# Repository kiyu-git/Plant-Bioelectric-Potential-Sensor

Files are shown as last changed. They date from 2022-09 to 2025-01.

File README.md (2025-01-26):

[日本語](https://github.com/kiyu-git/Plant-Bioelectric-Potential-Sensor) | [English](/README-en.md)

# Plant Bioelectric Potential Sensor

植物生体電位測定器

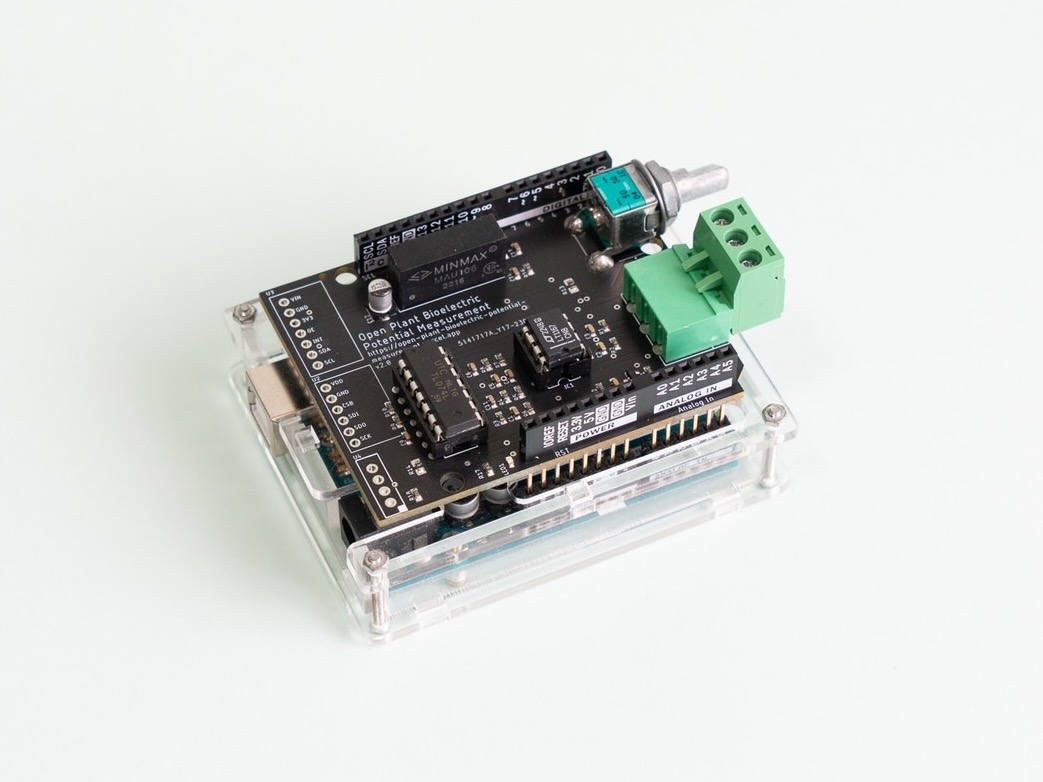
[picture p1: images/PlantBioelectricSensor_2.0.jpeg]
Plant-Bioelectric-Potential-Sensor


## Overview

開発した植物生体電位測定器の回路図等をまとめています。

なお、このリポジトリは、『[植物生体電位測定をオープンにするプロジェクト](https://open-plant-bioelectric-potential-measurement.vercel.app)』の一部です。

[こちら](https://kiyu-shop.booth.pm)からプロジェクトへの寄付、PCB 基板およびパーツのセットの購入ができます。

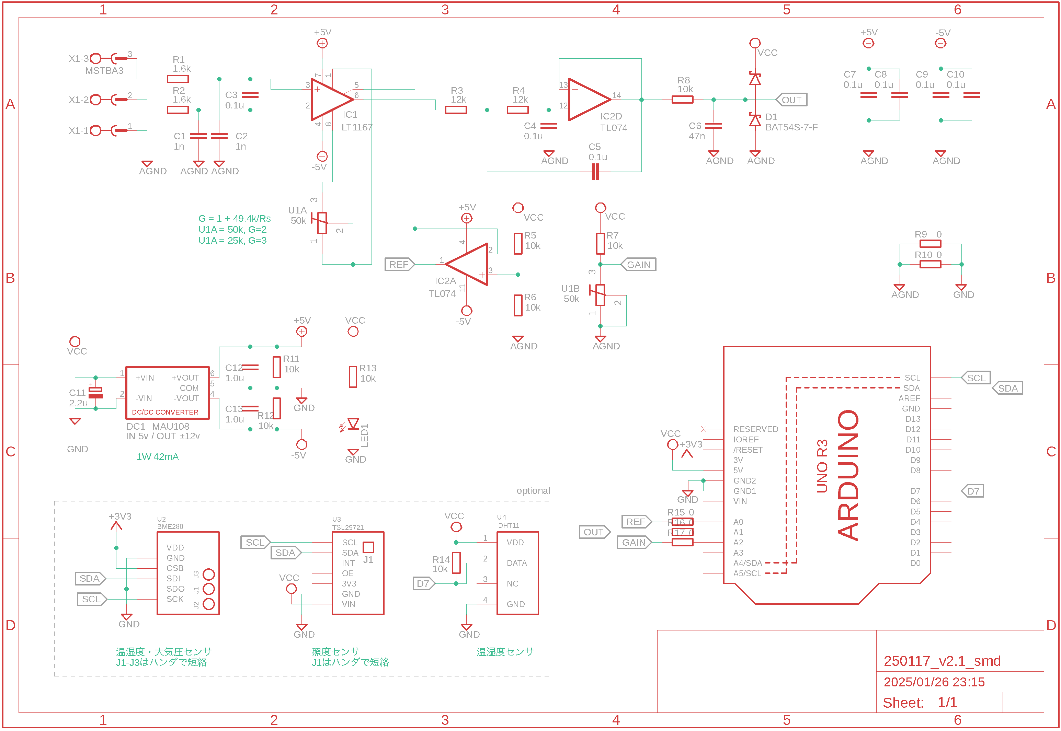
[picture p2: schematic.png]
Plant-Bioelectric-Potential-Sensor-schematic

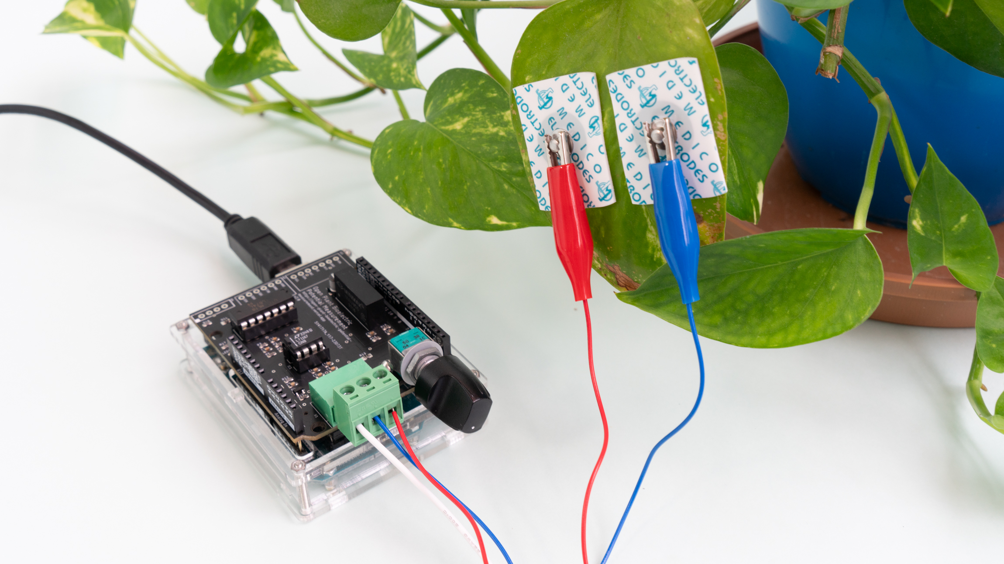
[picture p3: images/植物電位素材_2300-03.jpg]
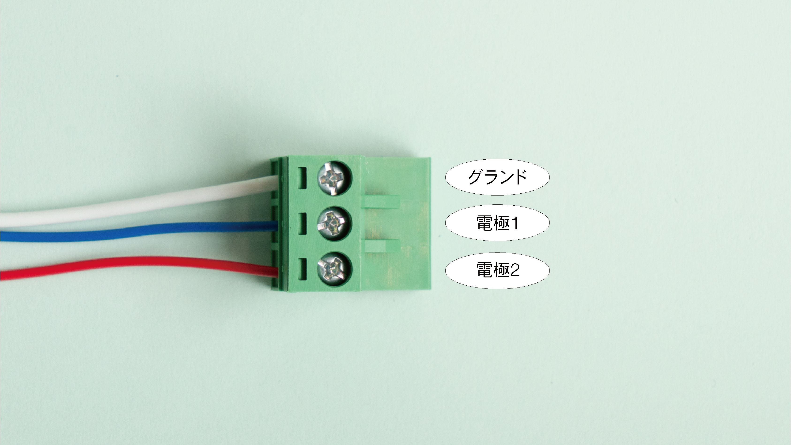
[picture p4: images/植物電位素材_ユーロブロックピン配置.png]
 

## Revision history

### v1.0.0

- 最初のモデル

### v1.1.0

- 部品の番号を振り直し
- [リンク](https://github.com/kiyu-git/Plant-Bioelectric-Potential-Sensor/tree/1f7dd3a86559b1f9ea93b5415610122e70b9b8db)

### v1.1.1

- 信号処理モジュール
  - 回路図を清書
  - 一部の抵抗の値を変更

### v2.0

- Arduino シールド規格に合わせ、拡張性を高めた。
- 回路構成の大幅な変更をおこなった。

### v2.1

- DC-DC コンバータを MAU 106 から MAU108 に変更
  - Arduino の ADC のフルレンジ（0 - 5V）での測定が可能になった。

## Requirement

植物生体電位測定器の組み立てに必要な部品一覧

**測定基板**

回路図から読み取ってください

**測定用ケーブル**

| Device Name | Value / Type | Need | Note |
| --- | --- | ---- | --- |
| ユーロブロックターミナル | | 1 | |
| 導線 | ~ 50cm | 3 | 赤青黒の 3 色があるとわかりやすい |
| みの虫クリップ | small | 3 | 赤青黒の 3 色があるとわかりやすい |
| 釘 | | 1 | 導電性のもの |
| 電極パッド | | 2 | 心電パッドなどを流用 |

## Usage

このリポジトリは、『[植物生体電位測定をオープンにするプロジェクト](https://open-plant-bioelectric-potential-measurement.vercel.app)』の一部です。

[植物生体電位測定の例 (YouTube)](https://www.youtube.com/embed/kBemMpVNFAs?si=k8SLGgCpc5z7__u_)

## Reference

- Forest Symphony: [https://special.ycam.jp/interlab/projects/forestsymphony.html](https://special.ycam.jp/interlab/projects/forestsymphony.html)
- LT1167 DataSheet: https://www.analog.com/media/en/technical-documentation/data-sheets/1167fc.pdf
- [and more...](https://docs.google.com/presentation/d/1Tm0e-mBNrTchN6YlGpvvomUZfy79yOtrTSNHG-l_jFg/edit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)

## Donation

[こちら](https://kiyu-shop.booth.pm/items/4141049)からプロジェクトへの寄付ができます。

## Author

質問等は twitter または[Issues](https://github.com/kiyu-git/Plant-Bioelectric-Potential-Sensor/issues)より

twitter: https://twitter.com/kyu_yukirinrin

website: https://untamable.work

## License

[GPL-3.0 license](https://github.com/kiyu-git/Plant-Bioelectric-Potential-Sensor/blob/main/LICENSE)

※ 共同研究や、案件依頼・相談も受け付けております。twitter DM または website よりご連絡ください。

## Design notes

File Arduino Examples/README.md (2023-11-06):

# Arduino Examples

## Basic

植物生体電位の増幅後の値、実際の値を測定し、シリアル通信で送信するプログラム

## Advanced

### upload_SORACOM

LTE モジュールと IoT クラウドサービス を利用したウェブ上でのデータ可視化の例。

SORACOM が販売している Arduino 用 LTE シールド LTE-M Shield for Arduino を植物生体電位測定器 と組み合わせ、SORACOM Harvest にデータを送信。

なお、LTE-M Shield for Arduino はアナログ入力ピン A1 を使用しており、起動すると植物生体電位を測定できない。 そのため、Reset ピンとデジタル入出力ピン D7 を接続し、A1 の値を読み取った後に、LTE モジュールを起動、データがアップロードできたら Reset し、A1 を解放している。

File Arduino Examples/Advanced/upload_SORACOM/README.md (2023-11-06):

# upload_SORACOM

植物生体電位測定器と LTE-M Shield for Arduino を利用するスケッチ例です。

This repository provides example sketches using plant bioelectric potential metar and LTE-M Shield for Arduino.

[arduino-dragino-unified](https://github.com/soracom-labs/arduino-dragino-unified/tree/main) を参考にしています。

## License

このリポジトリ配下に属するスケッチは [MIT ライセンス](./LICENSE-MIT)が適用されます。なお、スケッチが利用するライブラリはそれぞれのライセンスに従います。
たとえば、セルラー通信に利用する [TinyGSM](https://github.com/vshymanskyy/TinyGSM) ライブラリは [LGPL v3.0](./LICENSE-LGPLv3) ライセンスが適用されます。

The sketches in this repository are released under [The MIT License](./LICENSE-MIT), and libraries used by these sketches are subject to their respective licenses.
For example, the [TinyGSM](https://github.com/vshymanskyy/TinyGSM) library used for cellular communications is released under the [LGPL v3.0](./LICENSE-LGPLv3) license.

## Warning

このリポジトリ配下のスケッチは開発例であり、動作を保証するものではありません。また、このスケッチに記載されている内容の商用利用を想定していません。
利用にあたってはご自身の責任の範囲においてご利用ください。

The sketches in this repository are examples only and are not guaranteed to work. In addition, the content of this sketch is not intended for commercial use.
Please use them at your own risk.

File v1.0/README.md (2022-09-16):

## Requirement

植物生体電位測定器の組み立てに必要な部品一覧

部品番号 v1.0

| 測定部 | | | |
| --- | ----- | --- | --- |
| Part | Value | 備考 | URL |
| C1 | 47p | | |
| C2 | 47p | | |
| C3 | 0.1u  | | |
| C4 | 0.1u  | | |
| C8 | 0.1u  | | |
| IC1 | | LM324 | [参考](https://akizukidenshi.com/catalog/g/gI-14055/) |
| IC2 | | LT1167 | [参考](https://akizukidenshi.com/catalog/g/gI-02789/) |
| JP3 | | 5 連 pinheader（背が高いの推奨） | |
| LED2 | | 3mm LED（赤） | |
| R1 | 1k | | |
| R2 | 1k | | |
| R3 | 100k  | | |
| R4 | 10k | | |
| R5 | 10k | | |
| R6 | 4.7k  | | |
| R7 | 10k | | |
| R8 | 10k | | |
| R9 | 10k | | |
| R10 | 50k | 半固定抵抗 | |
| R12 | 100k  | | |
| R16 | 68k | | |
| R17 | 1k | | |
| R21 | 10k | | |
| R22 | 10k | | |
| U$2 | | 3.5mm ステレオミニジャック MJ-354W-SG | [参考](https://akizukidenshi.com/catalog/g/gC-15403/) |
| U$3 | | 2 連ボリューム | [参考](https://akizukidenshi.com/catalog/g/gP-12578/) |

| 電源部 | | | |
| --- | ----- | --- | --- |
| Part | Value | 備考 | URL |
| C9 | 47u | | |
| C10 | 47u | | |
| C11 | 47u | | |
| C12 | 0.1u  | | |
| C13 | 0.1u  | | |
| DC1 | | IN 5v/ OUT ±5v DC-DC コンバーター（MAU106） | [参考](https://akizukidenshi.com/catalog/g/gM-04133/) |
| JP1 | | 5 連 pinheader（背が高いの推奨） | |
| JP2 | | ※必要なし | |
| MODUL1 | | Arduino Nano | |
| R13 | 10k | | |
| R14 | 10k | | |

| 測定用銅線 | | | |
| --- | ----- | --- | --- |
| Part | Value | 備考 | URL |
| | | 3.5mm ステレオミニプラグ | |
| | | 銅線 | |
| | | ワニ口クリップ | |

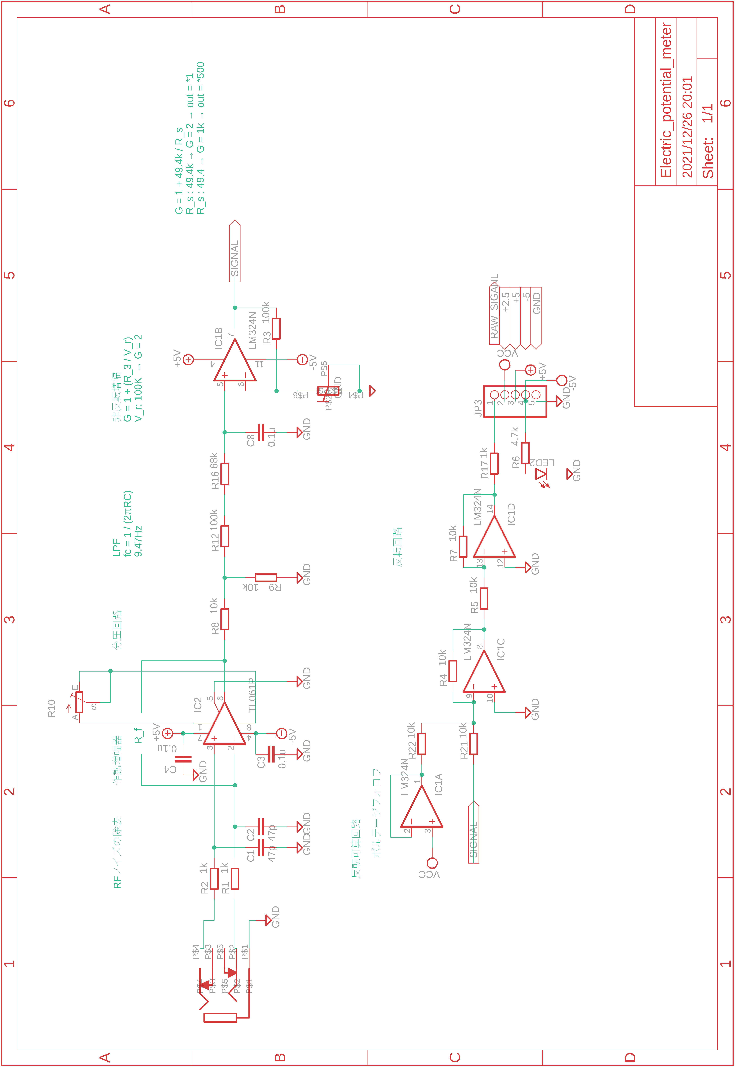
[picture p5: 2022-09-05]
v1.0/Signal Processing Module/images/circuit_sp_module.png

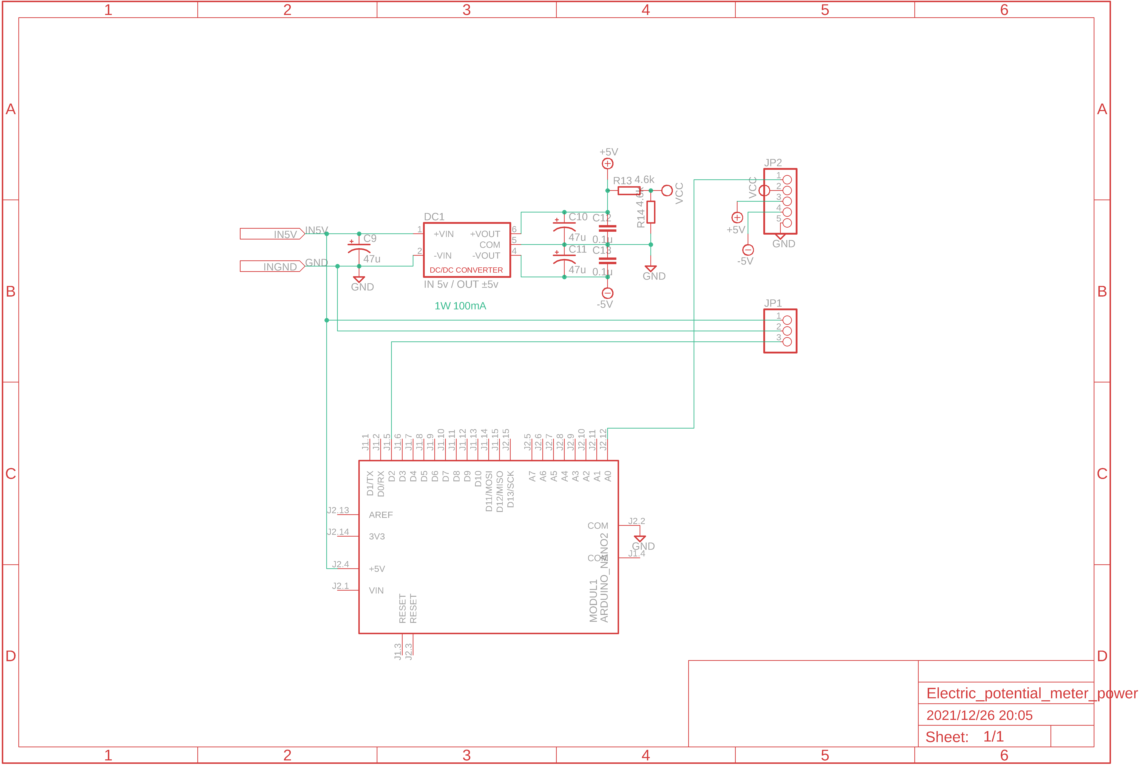
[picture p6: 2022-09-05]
v1.0/Power and ADC Module/images/circuit_power_module.png

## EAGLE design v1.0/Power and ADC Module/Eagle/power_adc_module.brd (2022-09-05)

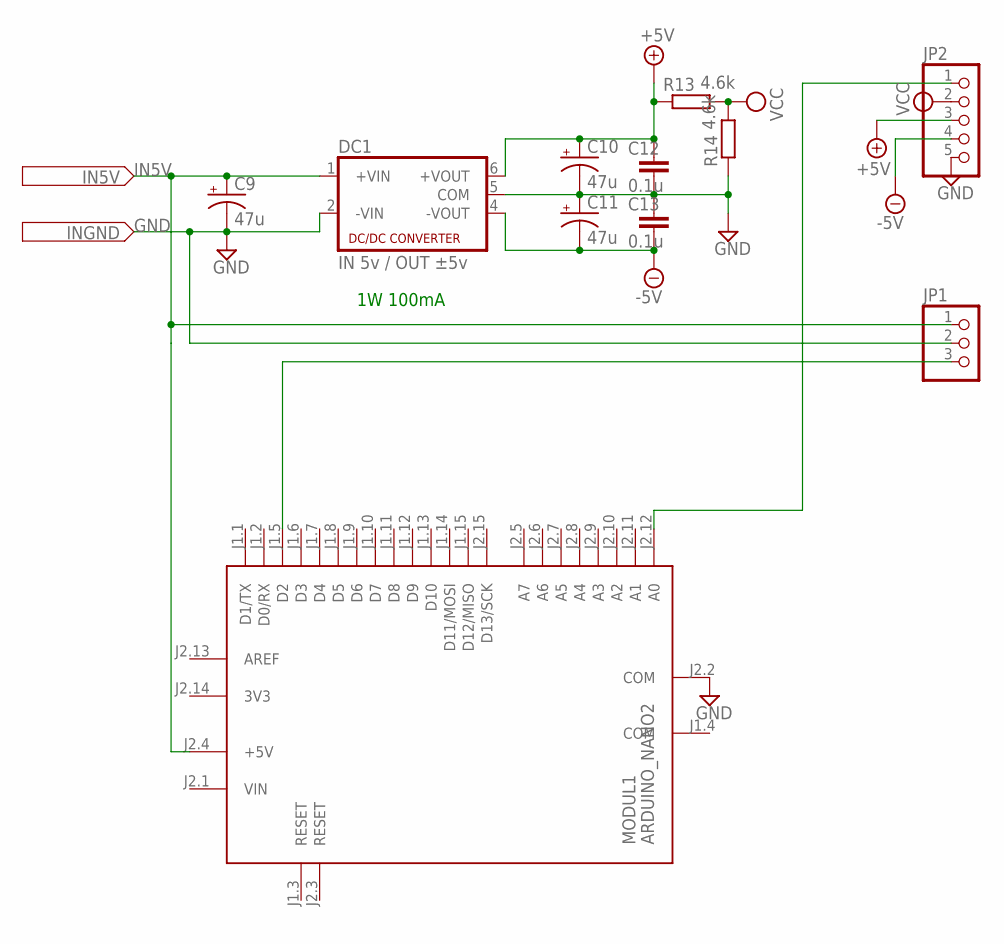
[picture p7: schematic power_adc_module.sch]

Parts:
C9, C10, C11: 47u; E2,5-5
C12, C13: 0.1u; C025-024X044
DC1: IN 5v / OUT ±5v; NMA
JP1: PINHD-1X3; 1X03
JP2: PINHD-1X5; 1X05
MODUL1: ARDUINO_NANO2
R13, R14: 4.6k; 0204/7

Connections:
3V3: MODUL1.J2.14 (3V3)
+5V: C10.+, C12.1, DC1.6 (+VOUT), JP2.3, R13.1
-5V: C11.-, C13.2, DC1.4 (-VOUT), JP2.4
AREF: MODUL1.J2.13 (AREF)
COM: MODUL1.J1.4 (COM)
GND: C9.-, C10.-, C11.+, C12.2, C13.1, DC1.2 (-VIN), DC1.5 (COM), JP1.2, JP2.5, MODUL1.J2.2 (COM), R14.1
IN5V: C9.+, DC1.1 (+VIN), JP1.1, MODUL1.J2.4 (+5V)
unnamed: JP2.1, MODUL1.J2.12 (A0)
unnamed: JP1.3, MODUL1.J1.5 (D2)
VCC: JP2.2, R13.2, R14.2
VIN: MODUL1.J2.1 (VIN)

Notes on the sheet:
1W 100mA

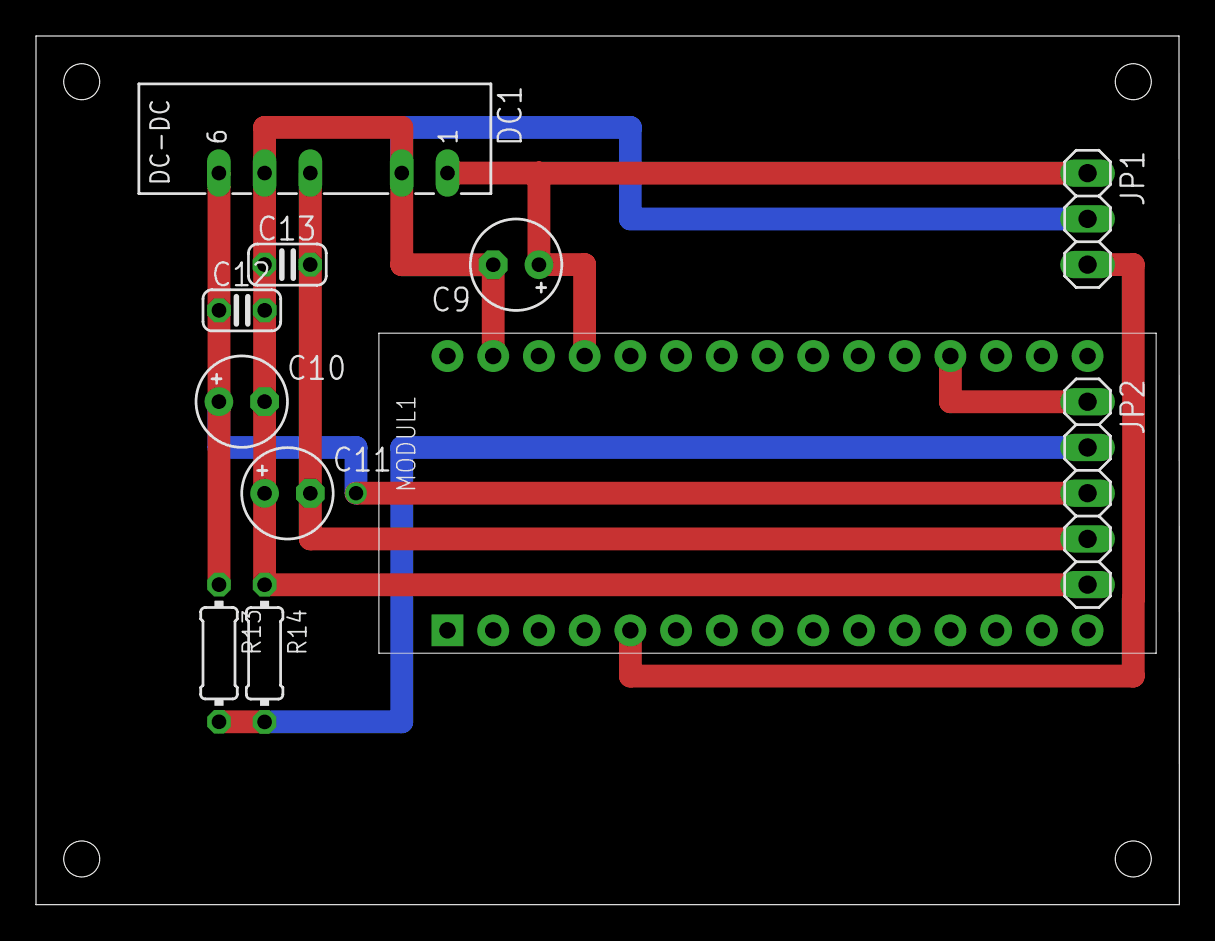
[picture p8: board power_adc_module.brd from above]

Board: 2 copper layers, 63.5 x 48.3 mm, 11 parts (0 on the bottom side), 7 nets.

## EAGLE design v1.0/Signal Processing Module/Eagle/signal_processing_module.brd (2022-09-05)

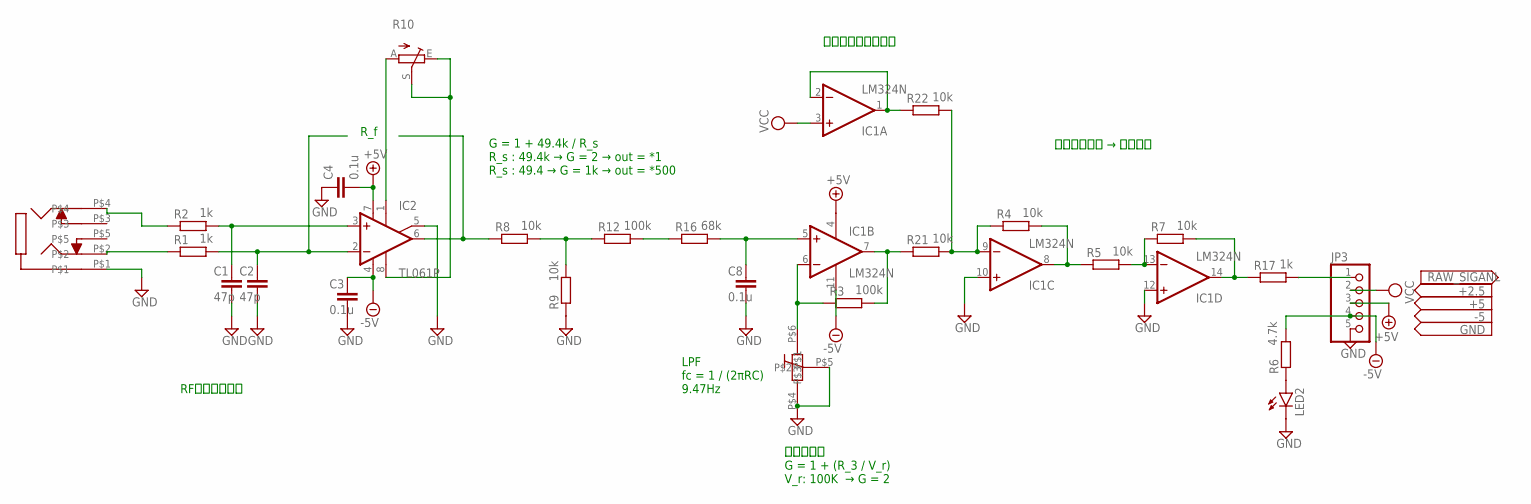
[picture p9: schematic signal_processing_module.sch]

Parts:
C1, C2: 47p; C025-024X044
C3, C4, C8: 0.1u; C025-024X044
IC1: LM324N; DIL14
IC2: TL061P; DIL08
JP3: PINHD-1X5; 1X05
LED2: LED3MM
R1, R2, R17: 1k; 0204/7
R3, R12: 100k; 0204/7
R4, R5, R7, R8, R9, R21, R22: 10k; 0204/7
R6: 4.7k; 0204/7
R10: TRIM_EU-RS3; RS3
R16: 68k; 0204/7
U$2: MJ-354W-SG
U$3: VR_2CH; 2CH_VR

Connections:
+5V: C4.2, IC1.4 (V+), IC2.7 (V+), JP3.3
-5V: C3.1, IC1.11 (V-), IC2.4 (V-), JP3.4, R6.2
GND: C1.2, C2.2, C3.2, C4.1, C8.2, IC1.10 (+IN), IC1.12 (+IN), IC2.5 (ON2), JP3.5, LED2.K (C), R9.1, U$2.P$1, U$3.P$4, U$3.P$5
unnamed: R1.1, U$2.P$2
unnamed: R2.1, U$2.P$4
unnamed: C1.1, IC2.3 (+IN), R2.2
unnamed: C2.1, IC2.2 (-IN), R1.2
unnamed: IC2.8 (OPT), R10.E, R10.S
unnamed: IC2.6 (OUT), R8.1
unnamed: IC2.1 (ON1), R10.A
unnamed: R12.2, R16.1
unnamed: IC1.13 (-IN), R5.2, R7.1
unnamed: JP3.1, R17.2
unnamed: LED2.A, R6.1
unnamed: IC1.6 (-IN), R3.1, U$3.P$6
unnamed: IC1.8 (OUT), R4.2, R5.1
unnamed: IC1.14 (OUT), R7.2, R17.1
unnamed: C8.1, IC1.5 (+IN), R16.2
unnamed: R8.2, R9.2, R12.1
unnamed: IC1.1 (OUT), IC1.2 (-IN), R22.1
unnamed: IC1.9 (-IN), R4.1, R21.2, R22.2
RAW_SIGNAL: IC1.7 (OUT), R3.2, R21.1
VCC: IC1.3 (+IN), JP3.2

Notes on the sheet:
G = 1 + 49.4k / R_s R_s : 49.4k → G = 2 → out = *1 R_s : 49.4 → G = 1k → out = *500
LPF fc = 1 / (2πRC) 9.47Hz
R_f
RFノイズの除去
非反転増幅 G = 1 + (R_3 / V_r) V_r: 100K → G = 2
ボルテージフォロワ
反転可算回路 → 反転回路

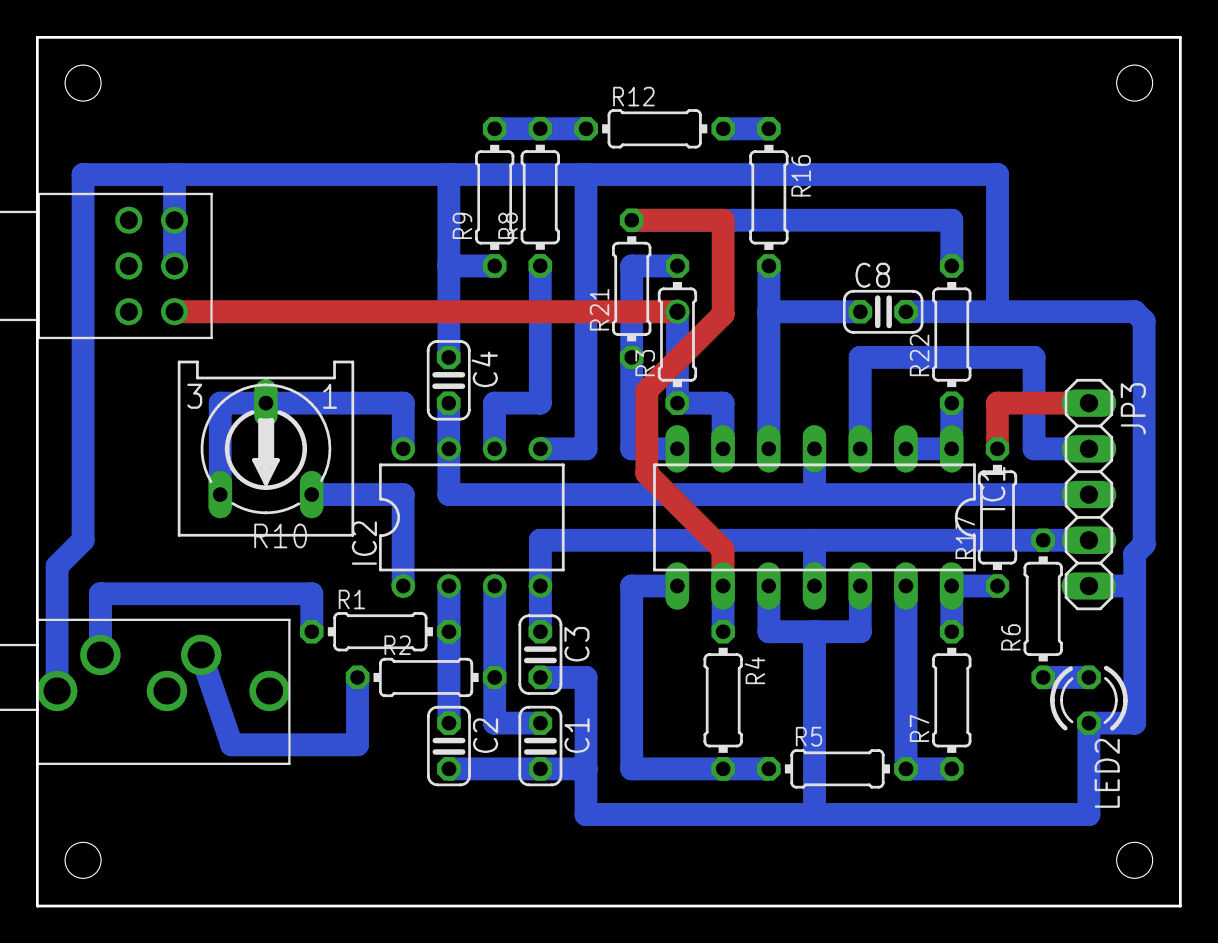
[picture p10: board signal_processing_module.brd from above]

Board: 2 copper layers, 63.5 x 48.3 mm, 26 parts (0 on the bottom side), 23 nets.

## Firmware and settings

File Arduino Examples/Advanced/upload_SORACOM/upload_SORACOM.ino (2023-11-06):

/*
 * 
 * This software is released under the MIT License, and libraries used by these sketches 
 * are subject to their respective licenses.
 * See also: https://github.com/soracom-labs/arduino-dragino-unified/README.md
 *
*/
#define VCC        (5.0)
#define ADCUNIT    (VCC / 1024.0) // V

#define CONSOLE Serial
#define INTERVAL_MS (1000)
#define ENDPOINT "uni.soracom.io"
#define SKETCH_NAME "send_uptime_with_soracom"
#define VERSION "1.0"

/* for LTE-M Shield for Arduino */
#define RX 10
#define TX 11
#define BAUDRATE 9600
#define BG96_RESET 15

#define TINY_GSM_MODEM_BG96
#include <TinyGsmClient.h>

#include <SoftwareSerial.h>
SoftwareSerial LTE_M_shieldUART(RX, TX);
TinyGsm modem(LTE_M_shieldUART);
TinyGsmClient ctx(modem);

int reset_Pin = 7;


void setup() {
 CONSOLE.begin(9600);
 digitalWrite(reset_Pin, HIGH);
 pinMode(reset_Pin, OUTPUT);
 Serial.println("----- setup -----");
}

void loop() {
  float Vx = (float)analogRead(A2)*ADCUNIT;  // 読み取ったアナログ値を電圧に変換(Rxにかかる電圧)
  float Rg = Vx * 10 / (VCC - Vx);
  float G = 1 + 49.4 / Rg;
  float Vref = (float)analogRead(A0)*ADCUNIT;
  float Vmeasure = (float)analogRead(A1)*ADCUNIT;
  float Vreal = (Vmeasure - Vref) / G;

  CONSOLE.print("測定値[V]:");
  CONSOLE.print(String(Vmeasure, 5));
  CONSOLE.print(",");
  CONSOLE.print("実際の生体電位[V]:");
  CONSOLE.print(String(Vreal, 5));
  CONSOLE.println("");

/////////////

//LTE-Mで送信するために、型変換を行う
float v = Vmeasure;
float v2 = Vref;
float vr = Rg*100;
float kg = G;
float vreal = Vreal;

char payload[320];
char v_str[10], v2_str[10], vr_str[10], kg_str[10], vreal_str[10];

dtostrf(v, 1, 4, v_str); // 小数点以下2桁の浮動小数点数を文字列に変換
dtostrf(v2, 1, 4, v2_str);
dtostrf(vr, 1, 4, vr_str);
dtostrf(kg, 2, 0, kg_str); // 整数部分のみを文字列に変換
dtostrf(vreal, 1, 4, vreal_str);

sprintf_P(payload, PSTR("{\"V\":%s, \"V2\":%s, \"VR\":%s, \"KG\":%s, \"Vreal\":%s}"), v_str, v2_str, vr_str, kg_str, vreal_str);
  
CONSOLE.println(payload);

delay(2000);

//setup

CONSOLE.println();
  CONSOLE.print(F("Welcome to ")); CONSOLE.print(SKETCH_NAME); CONSOLE.print(F(" ")); CONSOLE.println(VERSION);

  CONSOLE.print(F("resetting module "));
  pinMode(BG96_RESET,OUTPUT);
  digitalWrite(BG96_RESET,LOW);
  delay(1000);
  digitalWrite(BG96_RESET,HIGH);
  delay(1000);
  digitalWrite(BG96_RESET,LOW);
  CONSOLE.println(F(" done."));

  LTE_M_shieldUART.begin(BAUDRATE);

  CONSOLE.print(F("modem.restart()"));
  modem.restart();
  CONSOLE.println(F(" done."));

  CONSOLE.print(F("modem.getModemInfo(): "));
  String modemInfo = modem.getModemInfo();
  CONSOLE.println(modemInfo);

delay(500);

  CONSOLE.print(F("waitForNetwork()"));
  while (!modem.waitForNetwork()) CONSOLE.print(".");
  CONSOLE.println(F(" Ok."));

  CONSOLE.print(F("gprsConnect(soracom.io)"));
  modem.gprsConnect("soracom.io", "sora", "sora");
  CONSOLE.println(F(" done."));

  CONSOLE.print(F("isNetworkConnected()"));
  while (!modem.isNetworkConnected()) CONSOLE.print(".");
  CONSOLE.println(F(" Ok."));

  CONSOLE.print(F("My IP addr: "));
  IPAddress ipaddr = modem.localIP();
  CONSOLE.println(ipaddr); 

  /* connect */
  if (!ctx.connect(ENDPOINT, 80)) {
    CONSOLE.println(F("failed."));
    delay(3000);
    return;
  }
  /* send request */
  char hdr_buf[120];
  ctx.println(F("POST / HTTP/1.1"));
  sprintf_P(hdr_buf, PSTR("Host: %s"), ENDPOINT);
  ctx.println(hdr_buf);
  ctx.println(F("Content-Type: application/json"));
  sprintf_P(hdr_buf, PSTR("Content-Length: %d"), strlen(payload));
  ctx.println(hdr_buf);
  ctx.println();
  ctx.println(payload);
  /* receive response */
  while (ctx.connected()) {
    String line = ctx.readStringUntil('\n');
    CONSOLE.println(line);
    if (line == "\r") {
      CONSOLE.println(F("Response header received."));
      //break;
    }
  }
  // NOTE: response body is ignore
  ctx.stop();

  delay(3000);
  Serial.println("----- RESET -----");

  
  //リセット
  digitalWrite(reset_Pin, LOW);
}

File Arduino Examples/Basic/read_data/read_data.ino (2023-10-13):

// Open Plant Bioelectric Sensor v2.0 PIN LAYOUT
// A0 - リファレンス用
// A1 - 測定値用
// A2 - 可変抵抗計算用
// A4,A5 - I2C (optional)

#define VCC        (5.0)
#define ADCUNIT    (VCC / 1024.0) // V

void setup() {
  Serial.begin(9600);
}

void loop() {
  // analogReadの平均値を算出（電源ノイズを低減）
  long totalA0 = 0, totalA1 = 0, totalA2 = 0;
  float averageA0 = 0, averageA1 = 0, averageA2 = 0;

  for(int i = 0; i < 40; i++){
    analogRead(A0);
    totalA0 += analogRead(A0);
    analogRead(A1);
    totalA1 += analogRead(A1);
    analogRead(A2);
    totalA2 += analogRead(A2);
    delay(25);
  }
  averageA0 = (float)totalA0 / 40;
  averageA1 = (float)totalA1 / 40;
  averageA2 = (float)totalA2 / 40;

  // 増幅度を算出
  float Vx = averageA2 * ADCUNIT;
  float Rg = Vx * 10 / (VCC - Vx);
  float Gain = 1 + 49.4 / Rg;

  // 実際の生体電位を算出
  float Vref = averageA0 * ADCUNIT;
  float Vmeasure = averageA1 * ADCUNIT;
  float Vreal = (Vmeasure - Vref) / Gain;

  // 送信
  Serial.print("測定値[V]:");
  Serial.print(String(Vmeasure, 5));
  Serial.print(",");
  Serial.print("実際の生体電位[V]:");
  Serial.print(String(Vreal, 5));
  Serial.println();
}

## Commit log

2022-09-02 Add: Arduino sketch
2022-09-02 Add: CAM file and circuit img
    [power_adc_module.brd, power_adc_module.sch, signal_processing_module.brd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]
2022-09-05 Add: old files
    [power_adc_module.brd, power_adc_module.sch, signal_processing_module.brd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]
2022-09-05 Add: README 旧部品番号リストを追加
2022-09-05 Update: README 基板のバージョンに対応
2022-09-05 Update: リネーム
    [power_adc_module.brd, power_adc_module.sch, signal_processing_module.brd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]
2022-09-05 Update README 文章を修正
2022-09-05 Update: README 文章を修正
2022-09-05 Update: README リンクを修正
2022-09-13 Update: パーツリスト
2022-11-27 Move archive files
    [power_adc_module.brd, power_adc_module.sch, signal_processing_module.brd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]
2022-11-27 Update: v1.1.0
    [power_adc_module.brd, power_adc_module.sch, signal_processing_module.brd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]
2022-11-27 Add: Box data
    [back.dxf, bottom.dxf, front.dxf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]
2023-03-28 Add: 英語版READMEを追加
2023-03-28 Update: READMEを更新
2023-04-29 Update: ボーレートを9600に変更
2023-05-17 v1.1.1を更新
    [signal_processing_module.brd, signal_processing_module.sch]
2023-05-24 Update: リンクを修正
2023-08-30 Update: R16の値を修正
2023-10-13 Update: v2.0
    [back.dxf, bottom.dxf, front.dxf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]
2023-12-18 Update: 回路図を最新に更新
2025-01-26 Update: 誤表記を修正
